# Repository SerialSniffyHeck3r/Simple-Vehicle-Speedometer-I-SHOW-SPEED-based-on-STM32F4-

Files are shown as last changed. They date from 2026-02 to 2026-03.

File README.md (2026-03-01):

# 'I Show Speed' Portable Car Speedometer with Super High Sensitivity. 

Video

## 'I show Speed' 차량 대시보드용 속도 게이지: 한국어 설명

이 레포지토리는 회로도와 펌웨어, 케이스 STL 파일을 포함하고 있습니다. 

00년대 초반, GPS 네비게이션 제품이 비쌌던 그 시절 잠깐이나마 시장에 풀려 영광을 누릴 뻔 했던 GPS 안전운전 보조장치를 재해석한 차량용 속도계 프로젝트입니다.

- 방위, 거리, 고도, 경사도, 속도 지원
- 제로백 측정 기능 지원
- U-Blox 포맷 호환
- 속도 초과 시 경고 기능
- 단일 버튼 인터페이스
- GMT / 비프음 볼륨 / 화면 밝기 조절 설정 기능 내장
- 일출 일몰 계산하여 자동 밝기 적용하는 알고리즘 내장
- 플래시 메모리에 설정 값 저장
- 하드웨어 테스트 모드 

## Introduction

THIS REPOSITORY CONTAINS A COMPLETE BLUEPRINT AND FIRMWARE OF DIY CAR SPEEDO GAUGE AKA "I SHOW SPEED". 

So yeah.. I needed some device that I can easily carry, install, remove on a vehicle, and helps me avoid speeding. 
My initial thought was to make a device that warns speeding whenever I floor and sending her, with my leftover parts from one of my big main project.
However, the part that I use is clearly an overkill for this purpose. 
I mean, U-Blox M8 Series chip and STM32F4 for simple speed warning digital karen doesn't make any sense haha.
That's the start of the story.  Maybe I can integrate a whole lot of features that even a complete aftermarket HUD product doesn't provide? 

There are lots of similar product that falls into similar category - Tons of these are on sale from Aliexpress. 
They provide decent GPS sensitivity, some speed related feature. 
Pay more and you'll get a full pledged GIS based safe drive assistant system - clearly a waste of money, since at this point I would buy RAM mount instead..

And here I am - I am a well educated embedded engineer who can make things BETTER! 

## Design Origin

Here in korea, Car GPS was quite expensive on early 00s. Dedicated vehicle GPS unit is barely affordable.
Tech-savvy users can carry their PDAs that runs Windows CE or Windows Mobile 2003 with external GPS Module. 
Some companies even provide GPS Software like 'I-Navi' for those. However, Early PDAs all shared a similar fatal flaw - SRAM Backup. 
Once battery ran out, every settings and user applications installed on the PDA is completely gone, including GPS software.

So, small companies back then brought a simple idea. Most people use their GPS Navigation to check the location of speed cameras and avoid speeding. 
Then, Why don't we make a product that does not have an expensive processor and display, and just warns speed camera and show only necessary infos?

Those units have 8-bit MCU with SirfStar GPS chip. Most of them equipped with 4 digit segment display and very simple voice alert system, and was affordable.
People can install those small units on their dashboard and those device helped them to drive safe... and of course avoiding speed tickets, well... by driving carefully especially in front of speed cameras.

So my design was based on these unit, but now with more sensitive and fast (2Hz) GPS, 8 digit display and extended features.

## About the name of this project

I taught English as a part time job. and one of my student loved a youtube channel called I Show Speed.
And yeah.. This product pretty much literally shows a speed. That's it. 

## YOU MAY REQUIRE 
- MAX7219 8-Digit 7 Segment Display Unit (Everyone can afford it, go search aliexpress if you want)
- STM32 Black Pill Board W/ STM32F411CEU6. You can use any board if it contains the same chip.
- NEO-M8N or compatible U-Blox UART GPS Breakout Board. (Chinese clone board with official chip will work)
- Passive Buzzer for sound feedback feature
- A tactile button switch. No H/W debouncing circuit required as the firmware handle it
- Dark transparent film. It works without this, but you may want to slap in on the LED segment display as these display have shitty contrast without a film
- 3D Printed case. PET-G filament is recommended as the unit is placed on the car dashboard so it should be UV and heat resistent.

CARGPSTOY_F411.ZIP File contains a full project directory for STM32CubeIDE HAL. Import and build the project, then upload. 
Included STL file is a 3d print model for casing. Print and slap everything in a case. 

FEATURES:
- SAT STATUS: A Number of visible satellite blinks at 5Hz when there is no fix / Used satellite number when gps fix is availiable
- Current / Avg / Maximum Speed
- GPS Heading / Grade / Altitude / Time / Distance
- Automatic brightness control based on sunset / sunrise time
- 1-Field / 2-Field / 0-100 Measurement mode
- System setup is stored in an internal flash w/ wear leveling + CRC
- Hardware (Flash, RAM) Test feature
- Single Button User Interface
- Warning if current driving speed exceeds 150 / 160 / 170km/h 

Build and Enjoy! 
Bored? Add features. Fix bugs. FIne tune everything. 

## Cortex-M4, Isn't it overkill??

100% Agreed. STM32F4 is like a supercar for microproceor. Its like a Porsche when most commercially available cheapo 8-bit MCUs are a shitbox. 
BOM is a real issue when its in production, but since its a personal DIY project that people can download and make themselves, I valued more for ease of programming than an extreme cost cutting.

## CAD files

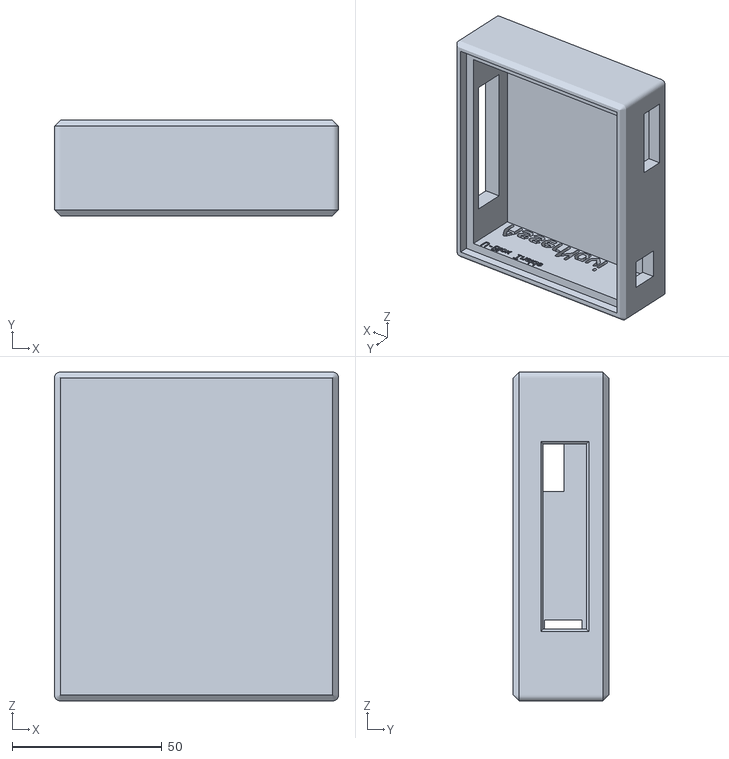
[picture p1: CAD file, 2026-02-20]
I_SHOW_SPEED.stl
95.0 x 32.0 x 110.0

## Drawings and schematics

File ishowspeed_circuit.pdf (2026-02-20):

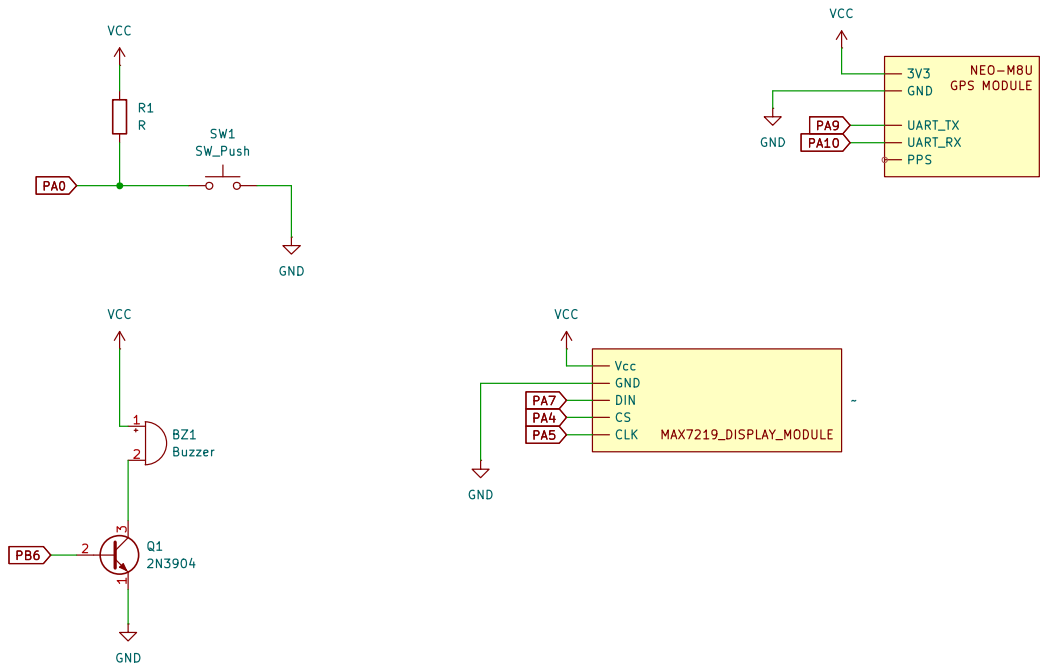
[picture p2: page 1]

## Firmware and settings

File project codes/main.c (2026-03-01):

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
/* Includes ------------------------------------------------------------------*/
#include "main.h"

/* USER CODE BEGIN Includes */
#include "gps_app.h"
#include "app_display.h"
#include "buzzer.h"
#include "max7219.h"

#include "settings_storage.h"   // ★ 추가

#include "hw_test.h"   // ★ dEu TEST 구현
/* USER CODE END Includes */

SPI_HandleTypeDef hspi1;

TIM_HandleTypeDef htim3;
TIM_HandleTypeDef htim4;

UART_HandleTypeDef huart1;

void SystemClock_Config(void);
static void MX_GPIO_Init(void);
static void MX_USART1_UART_Init(void);
static void MX_SPI1_Init(void);
static void MX_TIM3_Init(void);
static void MX_TIM4_Init(void);
/* USER CODE BEGIN 0 */


// 설정값 전역 변수
int8_t  g_cfg_timezone_hours = 9;   // GMT TIME, 기본 +9 (한국)
uint8_t g_cfg_brightness     = 2;   // MAX7219 밝기 레벨 1~3
uint8_t g_cfg_auto_mode      = 0;   // AUTO MODE: 0=off, 1=on

// Beep volume: 0~4 (0=mute, 4=max)
uint8_t g_cfg_beep_volume    = 4;



// 수정 후
typedef enum {
    SETUP_MENU_GMT = 0,
    SETUP_MENU_BRIGHTNESS,
    SETUP_MENU_AUTO,
    SETUP_MENU_BEEP_VOL,
    SETUP_MENU_HWTEST
} setup_menu_t;















typedef enum {
    KEY_EVENT_NONE = 0,
    KEY_EVENT_SHORT,
    KEY_EVENT_LONG
} key_event_t;

typedef struct {
    uint8_t  stable_level;     // 디바운스 이후 안정 레벨 (1: released, 0: pressed)
    uint8_t  last_sample;      // 마지막 raw 샘플
    uint32_t last_change_ms;   // last_sample 변경 시각
    uint8_t  pressed;          // 눌린 상태로 인정 중인지
    uint32_t press_start_ms;   // 눌리기 시작한 시각
    uint8_t  long_sent;        // long event 이미 보냈는지
} key_state_t;

static key_state_t s_key_pa0;

#define KEY_DEBOUNCE_MS      30u
#define KEY_LONGPRESS_MS    800u
#define KEY_SHORT_MIN_MS     50u   // 50ms 이하는 노이즈로 무시

// PA0 raw 읽기 (풀업 + 스위치 → GND 가정)
static inline uint8_t Key_PA0_ReadRaw(void)
{
    GPIO_PinState s = HAL_GPIO_ReadPin(GPIOA, GPIO_PIN_0);
    return (s == GPIO_PIN_RESET) ? 0u : 1u;  // 0 = pressed
}

static void Key_Init(void)
{
    uint32_t now = HAL_GetTick();
    uint8_t lvl  = Key_PA0_ReadRaw();

    memset(&s_key_pa0, 0, sizeof(s_key_pa0));
    s_key_pa0.stable_level   = lvl;
    s_key_pa0.last_sample    = lvl;
    s_key_pa0.last_change_ms = now;
}

static key_event_t Key_Poll(uint32_t now_ms)
{
    key_event_t ev = KEY_EVENT_NONE;
    uint8_t raw = Key_PA0_ReadRaw();

    // 샘플 변경 시 디바운스 타이머 리셋
    if (raw != s_key_pa0.last_sample) {
        s_key_pa0.last_sample    = raw;
        s_key_pa0.last_change_ms = now_ms;
    }

    // 디바운스 완료되면 stable_level 반영
    if ((now_ms - s_key_pa0.last_change_ms) >= KEY_DEBOUNCE_MS) {
        if (s_key_pa0.stable_level != raw) {
            s_key_pa0.stable_level = raw;

            if (raw == 0u) {
                // 눌림 시작
                s_key_pa0.pressed        = 1u;
                s_key_pa0.press_start_ms = now_ms;
                s_key_pa0.long_sent      = 0u;
            } else {
                // 떼어짐
                if (s_key_pa0.pressed) {
                    uint32_t dur = now_ms - s_key_pa0.press_start_ms;

                    if (!s_key_pa0.long_sent &&
                        dur >= KEY_SHORT_MIN_MS &&
                        dur < KEY_LONGPRESS_MS) {
                        ev = KEY_EVENT_SHORT;
                    }
                    s_key_pa0.pressed = 0u;
                }
            }
        }
    }

    // 길게 누르기 판정
    if (s_key_pa0.pressed && !s_key_pa0.long_sent) {
        uint32_t dur = now_ms - s_key_pa0.press_start_ms;
        if (dur >= KEY_LONGPRESS_MS) {
            s_key_pa0.long_sent = 1u;
            ev = KEY_EVENT_LONG;
        }
    }

    return ev;
}








// ---------------------- 부팅 설정 모드 ----------------------

static void RunHardwareSelfTest(void)
{
    /* dEu tESt: FLASH + RAM 테스트 1회 실행 (블로킹) */
    HW_RunSelfTest();
}


static void EnterSetupMode(void)
{
    setup_menu_t menu = SETUP_MENU_GMT;
    uint8_t      done = 0u;

    // 설정 모드 진입 시 화면 한번 깨끗하게
    max7219_Clean();

    while (!done) {
        uint32_t now = HAL_GetTick();

        // 현재 메뉴 화면 표시
        switch (menu) {
        case SETUP_MENU_GMT:
            APP_Display_ShowSetupGMT(g_cfg_timezone_hours);
            break;

        case SETUP_MENU_BRIGHTNESS:
            APP_Display_ShowSetupBrightness(g_cfg_brightness);
            break;

        case SETUP_MENU_AUTO:
            APP_Display_ShowSetupAutoMode((g_cfg_auto_mode != 0u));
            break;

        case SETUP_MENU_BEEP_VOL:
            APP_Display_ShowSetupBeepVolume(g_cfg_beep_volume);
            break;

        case SETUP_MENU_HWTEST:
            APP_Display_ShowSetupHwTest();
            break;

        default:
            done = 1u;
            continue;
        }

        // 버튼 이벤트 처리
        key_event_t kev = Key_Poll(now);
        if (kev == KEY_EVENT_SHORT) {
            switch (menu) {
            case SETUP_MENU_GMT:
                // 타임존 +1씩 증가, 끝까지 가면 -12로 순환
                if (g_cfg_timezone_hours < 14) {
                    g_cfg_timezone_hours++;
                } else {
                    g_cfg_timezone_hours = -12;
                }
                APP_Display_SetTimezone(g_cfg_timezone_hours);
                break;

            case SETUP_MENU_BRIGHTNESS:
                // 1 → 2 → 3 → 1 순환
                if (g_cfg_brightness < 3u) {
                    g_cfg_brightness++;
                } else {
                    g_cfg_brightness = 1u;
                }
                // 바로 MAX7219 글로벌 밝기 테이블에 반영
                APP_Display_SetBrightnessLevel(g_cfg_brightness);
                break;

            case SETUP_MENU_AUTO:
                // on/off 토글
                g_cfg_auto_mode ^= 1u;
                APP_Display_SetAutoModeEnabled((bool)(g_cfg_auto_mode != 0u));
                break;

            case SETUP_MENU_BEEP_VOL:
                // 0 → 1 → 2 → 3 → 4 → 0 순환 (0=mute, 4=max)
                if (g_cfg_beep_volume < 4u) {
                    g_cfg_beep_volume++;
                } else {
                    g_cfg_beep_volume = 0u;
                }

                APP_Display_ShowSetupBeepVolume(g_cfg_beep_volume);
                Buzzer_SetVolume(g_cfg_beep_volume);
                break;


            case SETUP_MENU_HWTEST:
            	RunHardwareSelfTest();
                break;

            default:
                break;
            }
        } else if (kev == KEY_EVENT_LONG) {
            switch (menu) {
            case SETUP_MENU_GMT:
            case SETUP_MENU_BRIGHTNESS:
            case SETUP_MENU_AUTO:
            	menu = (setup_menu_t)((int)menu + 1);

                break;

            case SETUP_MENU_BEEP_VOL:
                menu = (setup_menu_t)((int)menu + 1);
                break;

            case SETUP_MENU_HWTEST:
                // 하드웨어 테스트 1회 실행 후 SAT STATUS로 탈출
                done = 1u;
                break;


            default:
                done = 1u;
                break;
            }
        }

        // GPS 상태는 계속 갱신해서 FIX 유지
        APP_GPS_Update();

        // 너무 빠른 루프 방지
        HAL_Delay(10);
    }

    // 설정이 끝났으니 현재 전역 설정값을 플래시에 저장
    app_settings_t cfg;
    // 수정 후
    cfg.timezone_hours = g_cfg_timezone_hours;
    cfg.brightness     = g_cfg_brightness;
    cfg.auto_mode      = g_cfg_auto_mode;
    cfg.beep_volume    = g_cfg_beep_volume;

    Settings_Save(&cfg);
    // 설정 메뉴를 모두 지나치면 SAT STATUS 화면으로
    APP_Display_SetMode(APP_DISPLAY_SAT_STATUS);
}

static void CheckBootAndEnterSetup(void)
{
    const uint32_t window_ms    = 1000u;  // 부팅 후 체크 전체 윈도우
    const uint32_t min_press_ms = 150u;   // 이 시간 이상 연속 LOW여야 인정

    uint32_t start      = HAL_GetTick();
    uint32_t low_start  = 0u;
    uint8_t  enter      = 0u;

    while ((HAL_GetTick() - start) < window_ms) {
        uint32_t now = HAL_GetTick();
        uint8_t  raw = Key_PA0_ReadRaw();  // 0 = pressed (active-low)

        if (raw == 0u) {  // LOW = 눌림
            if (low_start == 0u) {
                // 처음 LOW로 떨어진 시점 기억
                low_start = now;
            } else {
                // LOW 상태가 min_press_ms 이상 유지되면 "진짜로 누르고 있음"
                if ((now - low_start) >= min_press_ms) {
                    enter = 1u;
                    break;
                }
            }
        } else {
            // 중간에 한 번이라도 HIGH로 올라가면 연속성 끊기므로 초기화
            low_start = 0u;
        }
    }

    if (enter) {
        EnterSetupMode();
    }
}







void HAL_TIM_PeriodElapsedCallback(TIM_HandleTypeDef *htim)
{
    if (htim->Instance == TIM3) {
        // 100 ms tick
        APP_Display_BlinkTick_100ms();
        Buzzer_Tick_100ms();   // 3번에서 만들 Buzzer 모듈
    }
}

/* USER CODE END 0 */

/**
  * @brief  The application entry point.
  * @retval int
  */
int main(void)
{

  /* MCU Configuration--------------------------------------------------------*/

  /* Reset of all peripherals, Initializes the Flash interface and the Systick. */
  HAL_Init();

  /* Configure the system clock */
  SystemClock_Config();

  /* Initialize all configured peripherals */
  MX_GPIO_Init();
  MX_USART1_UART_Init();
  MX_SPI1_Init();
  MX_TIM3_Init();
  MX_TIM4_Init();
  /* USER CODE BEGIN 2 */
  HAL_TIM_Base_Start_IT(&htim3);



  // MAX7219 초기화
  max7219_Init(0x08);   // 밝기: 0x00 ~ 0x0F
  max7219_Clean();

  APP_Display_RunBrightnessSweepTest();



  APP_GPS_Init();
  APP_Display_Init();




  app_settings_t stored;
  bool loaded = Settings_Load(&stored);
  if (loaded) {
      g_cfg_timezone_hours = stored.timezone_hours;
      g_cfg_brightness     = stored.brightness;
      g_cfg_auto_mode      = stored.auto_mode;

      uint8_t v = stored.beep_volume;
      if (v > 4u) {
          v = 4u;  // 범위 밖이면 최대 볼륨
      }
      g_cfg_beep_volume = v;
  } else {
      // 설정이 없으면: 기본 비프 볼륨 4
      g_cfg_beep_volume = 4u;
  }

  if (g_cfg_beep_volume > 4u) {
      g_cfg_beep_volume = 4u;
  }

  // 속도 클램프는 이제 별도 설정 없이 고정 (기본: off)
  APP_Display_SetSpeedClamp2HzEnabled(false);

  APP_Display_SetTimezone(g_cfg_timezone_hours);
  APP_Display_SetAutoModeEnabled(g_cfg_auto_mode != 0u);
  APP_Display_SetBrightnessLevel(g_cfg_brightness);

  Key_Init();          // 버튼 초기화
  Buzzer_SetVolume(g_cfg_beep_volume);
  Buzzer_Init();       // Buzzer 시작

  HAL_Delay(400);

  Buzzer_PlaySequence(BEEP_SEQ_START);  // 전원 ON 멜로디

  CheckBootAndEnterSetup();
  /* USER CODE END 2 */

  /* Infinite loop */
  /* USER CODE BEGIN WHILE */
  while (1)
  {
    /* USER CODE END WHILE */

    /* USER CODE BEGIN 3 */

	    uint32_t now = HAL_GetTick();

	    // 키 폴링
	    key_event_t kev = Key_Poll(now);
	    if (kev == KEY_EVENT_SHORT) {
	        // 짧게 누름 → 메뉴 한 칸 증가
	        APP_Display_NextMode();
	        Buzzer_PlaySequence(BEEP_SEQ_USER8);
	    } else if (kev == KEY_EVENT_LONG) {
	        // 길게 누름
	        //  - 뱅크 전환:
	        //    1 FIELD → 2 FIELD → 0 to 100 → 1 FIELD → ...
	        //  - 전환 시 "1 FIELd" / "2 FIELd" / "0 to 100" 잠깐 표시
	        APP_Display_NextBank();
	        Buzzer_PlaySequence(BEEP_SEQ_USER9);
	    }

	    // GPS 상태 갱신
	    APP_GPS_Update();

	    // 현재 모드에 따라 7-seg 화면 업데이트
	    APP_Display_Update();


  }
  /* USER CODE END 3 */
}

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


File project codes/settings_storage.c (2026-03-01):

/* settings_storage.c */

#include "settings_storage.h"
#include "main.h"
#include <string.h>
#include <stddef.h>

/* 아무 의미 없는 매직 값 (레코드 식별용) */
#define SETTINGS_MAGIC               (0x43504647u)  /* 'G','F','P','C' 같은 느낌 */

/* STM32F411CEU6 (512KB Flash)
 * Sector 0: 0x08000000, 16KB
 * ...
 * Sector 4: 0x08010000, 64KB
 * Sector 5: 0x08020000, 128KB
 * Sector 6: 0x08040000, 128KB
 * Sector 7: 0x08060000, 128KB
 *
 * => 끝부분 3섹터 = 5,6,7 사용 (총 384KB)
 */
#define SETTINGS_FLASH_BASE          (0x08020000u)  /* Sector 5 시작 */
#define SETTINGS_FLASH_END           (0x08080000u)  /* Flash 끝 주소 (exclusive) */

#define SETTINGS_FLASH_SECTOR_FIRST  FLASH_SECTOR_5
#define SETTINGS_FLASH_SECTOR_COUNT  (3u)           /* 5,6,7 섹터 사용 */

typedef struct {
    uint32_t       magic;
    uint32_t       seq;
    app_settings_t payload;
    uint32_t       crc32;
} settings_record_t;

#define SETTINGS_RECORD_SIZE   (sizeof(settings_record_t))

/* CRC32 (Ethernet 폴리노미얼) */
static uint32_t crc32_calc(const uint8_t *data, size_t len)
{
    uint32_t crc = 0xFFFFFFFFu;
    for (size_t i = 0; i < len; ++i) {
        crc ^= (uint32_t)data[i];
        for (uint32_t bit = 0; bit < 8u; ++bit) {
            uint32_t mask = (uint32_t)-(int32_t)(crc & 1u);
            crc = (crc >> 1) ^ (0xEDB88320u & mask);
        }
    }
    return ~crc;
}

/* 플래시 영역을 스캔해서
 *  - 마지막으로 유효한 레코드의 seq, 주소
 *  - 다음에 쓸 수 있는 빈 슬롯 주소
 * 를 찾는다. (웨어 레벨링용 로그 스캔)
 */
static bool settings_scan(uint32_t *out_last_seq,
                          uint32_t *out_last_addr,
                          uint32_t *out_next_free_addr)
{
    uint32_t last_seq      = 0u;
    uint32_t last_addr     = 0u;
    bool     have_last     = false;

    uint32_t addr = SETTINGS_FLASH_BASE;
    const uint32_t end = SETTINGS_FLASH_END;

    while ((addr + SETTINGS_RECORD_SIZE) <= end) {
        const settings_record_t *rec = (const settings_record_t *)addr;

        uint32_t magic = rec->magic;

        /* 플래시 erase 상태: 0xFFFFFFFF...
         * 첫 번째 지워진 슬롯을 만나면 그 뒤는 전부 빈 영역이라고 가정
         */
        if (magic == 0xFFFFFFFFu) {
            break;
        }

        if (magic != SETTINGS_MAGIC) {
            addr += SETTINGS_RECORD_SIZE;
            continue;
        }

        uint32_t calc_crc = crc32_calc((const uint8_t *)&rec->magic,
                                       sizeof(settings_record_t) - sizeof(uint32_t));
        if (calc_crc != rec->crc32) {
            addr += SETTINGS_RECORD_SIZE;
            continue;
        }

        if (!have_last || (rec->seq > last_seq)) {
            have_last = true;
            last_seq  = rec->seq;
            last_addr = addr;
        }

        addr += SETTINGS_RECORD_SIZE;
    }

    if (out_last_seq) {
        *out_last_seq = last_seq;
    }
    if (out_last_addr) {
        *out_last_addr = last_addr;
    }

    if (out_next_free_addr) {
        if ((addr + SETTINGS_RECORD_SIZE) <= end) {
            *out_next_free_addr = addr;
        } else {
            *out_next_free_addr = 0u; /* 더 쓸 곳 없음 */
        }
    }

    return have_last;
}

/* 플래시에서 마지막 유효 설정을 읽기 */
bool Settings_Load(app_settings_t *out)
{
    if (!out) {
        return false;
    }

    uint32_t last_seq  = 0u;
    uint32_t last_addr = 0u;
    uint32_t next_addr = 0u;

    (void)next_addr;

    bool have_last = settings_scan(&last_seq, &last_addr, &next_addr);
    if (!have_last) {
        return false;
    }

    const settings_record_t *rec = (const settings_record_t *)last_addr;
    *out = rec->payload;
    return true;
}
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

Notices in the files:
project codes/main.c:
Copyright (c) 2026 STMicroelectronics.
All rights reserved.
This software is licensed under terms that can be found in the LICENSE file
